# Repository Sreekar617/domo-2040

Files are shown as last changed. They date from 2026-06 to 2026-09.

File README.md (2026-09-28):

# domo-2040
A custom microcontroller built around the RP2040





## Features
* RP2040 microcontroller
* 27 GPIO pins
* 16MB flash memory
* Onboard user button (GPIO24)
* Onboard user LED (GPIO25)
* USB-C connection
* Compatible with Pi Pico footprint
* Super cool decoration
* Cute Domos
## Why?
I use devboards like the Pi Pico all the time, but I never really understood how they worked or anything. Specifically, I was curious as to why projects tend to use premade devboards such as Pi Picos rather than just use a plain RP2040. So naturally, I decided the best way to learn was to make one myself. Also, funnily enough the BOM comes out to about half the retail price of the Pico before countimg one-time assembly fees, which means if I were to theoretically mass produce this me and my friends could get devboards at about half price. 
## BOM
| Component | Specification | Quantity | LCSC Part # | Price |
|---|---|---|---|---|
| Capacitor 0402 | 1uF | 2 | C52923 | $0.02 |
| Capacitor 0402 | 0.1uF | 11 | C1525 | $0.06 |
| Capacitor 0402 | 33pF | 2 | C1562 | $0.02 |
| Capacitor 0603 | 10uF | 2 | C19702 | $0.20 |
| Diode SOD-323 | Schottky | 1 | C191023 | $0.02 |
| LED 0603 | White LED | 1 | C2290 | $0.02 |
| USB C Receptacle | USB C | 1 | C2765186 | $0.21 |
| Resistor 0402 | 5.1k | 2 | C25905 | $0.01 |
| Resistor 0402 | 27 | 2 | C25156 | $0.02 |
| Resistor 0402 | 1k | 3 | C11702 | $0.02 |
| Resistor 0402 | 10k | 2 | C25744 | $0.01 |
| Switch | Alps SKRK | 2 | C720477 | $0.11 |
| MCU | RP2040 | 1 | C2040 | $2.00 |
| Flash Chip | 128Mbit | 1 | C97521 | $2.65 |
| LDO SOT-23 | 5v->3v3 | 1 | C5446 | $0.20 |
| Crystal | 12MHz | 1 | C9002 | $0.20 |
| ~~**Soldering Iron**~~ | | 1 | stole it from a friend lol |~~$20~~ |

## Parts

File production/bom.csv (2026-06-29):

Designator | Footprint | Quantity | Value | LCSC Part #
C1, C12 | 0402 | 2 | 1uF | C52923
C10, C11, C17, C2, C3, C4, C5, C6, C7, C8, C9 | 0402 | 11 | 0.1uF | C1525
C13, C14 | 0402 | 2 | 33pF | C1562
C15, C16 | 0603 | 2 | 10uF | C19702
D1 | D_SOD-323 | 1 | 1N5819WS | C191023
D2 | 0603 | 1 | LED | C2290
J1 | USB_C_Receptacle_HRO_TYPE-C-31-M-12 | 1 | USB_C_Receptacle_USB2.0_14P | C2765186
J2, J3 | PinHeader_1x20_P2.54mm_Vertical | 2 | Conn_01x20 | C50981
J4 | PinHeader_1x03_P2.54mm_Vertical | 1 | Conn_01x03 | C24980
R1, R2 | 0402 | 2 | 5.1k | C25905
R3, R4 | 0402 | 2 | 27 | C25156
R5, R7, R8 | 0402 | 3 | 1k | C11702
R6, R9 | 0402 | 2 | 10k | C25744
SW1, SW2 | SW_Push_SPST_NO_Alps_SKRK | 2 | SW_Push | C720477
U1 | QFN-56-1EP_7x7mm_P0.4mm_EP3.2x3.2mm | 1 | RP2040 | C2040
U3 | SOIC-8_5.3x5.3mm_P1.27mm | 1 | W25Q128JVS | C97521
U4 | SOT-23 | 1 | MCP1700x-330xxTT | C5446
Y1 | Crystal_SMD_3225-4Pin_3.2x2.5mm | 1 | 12MHz | C9002

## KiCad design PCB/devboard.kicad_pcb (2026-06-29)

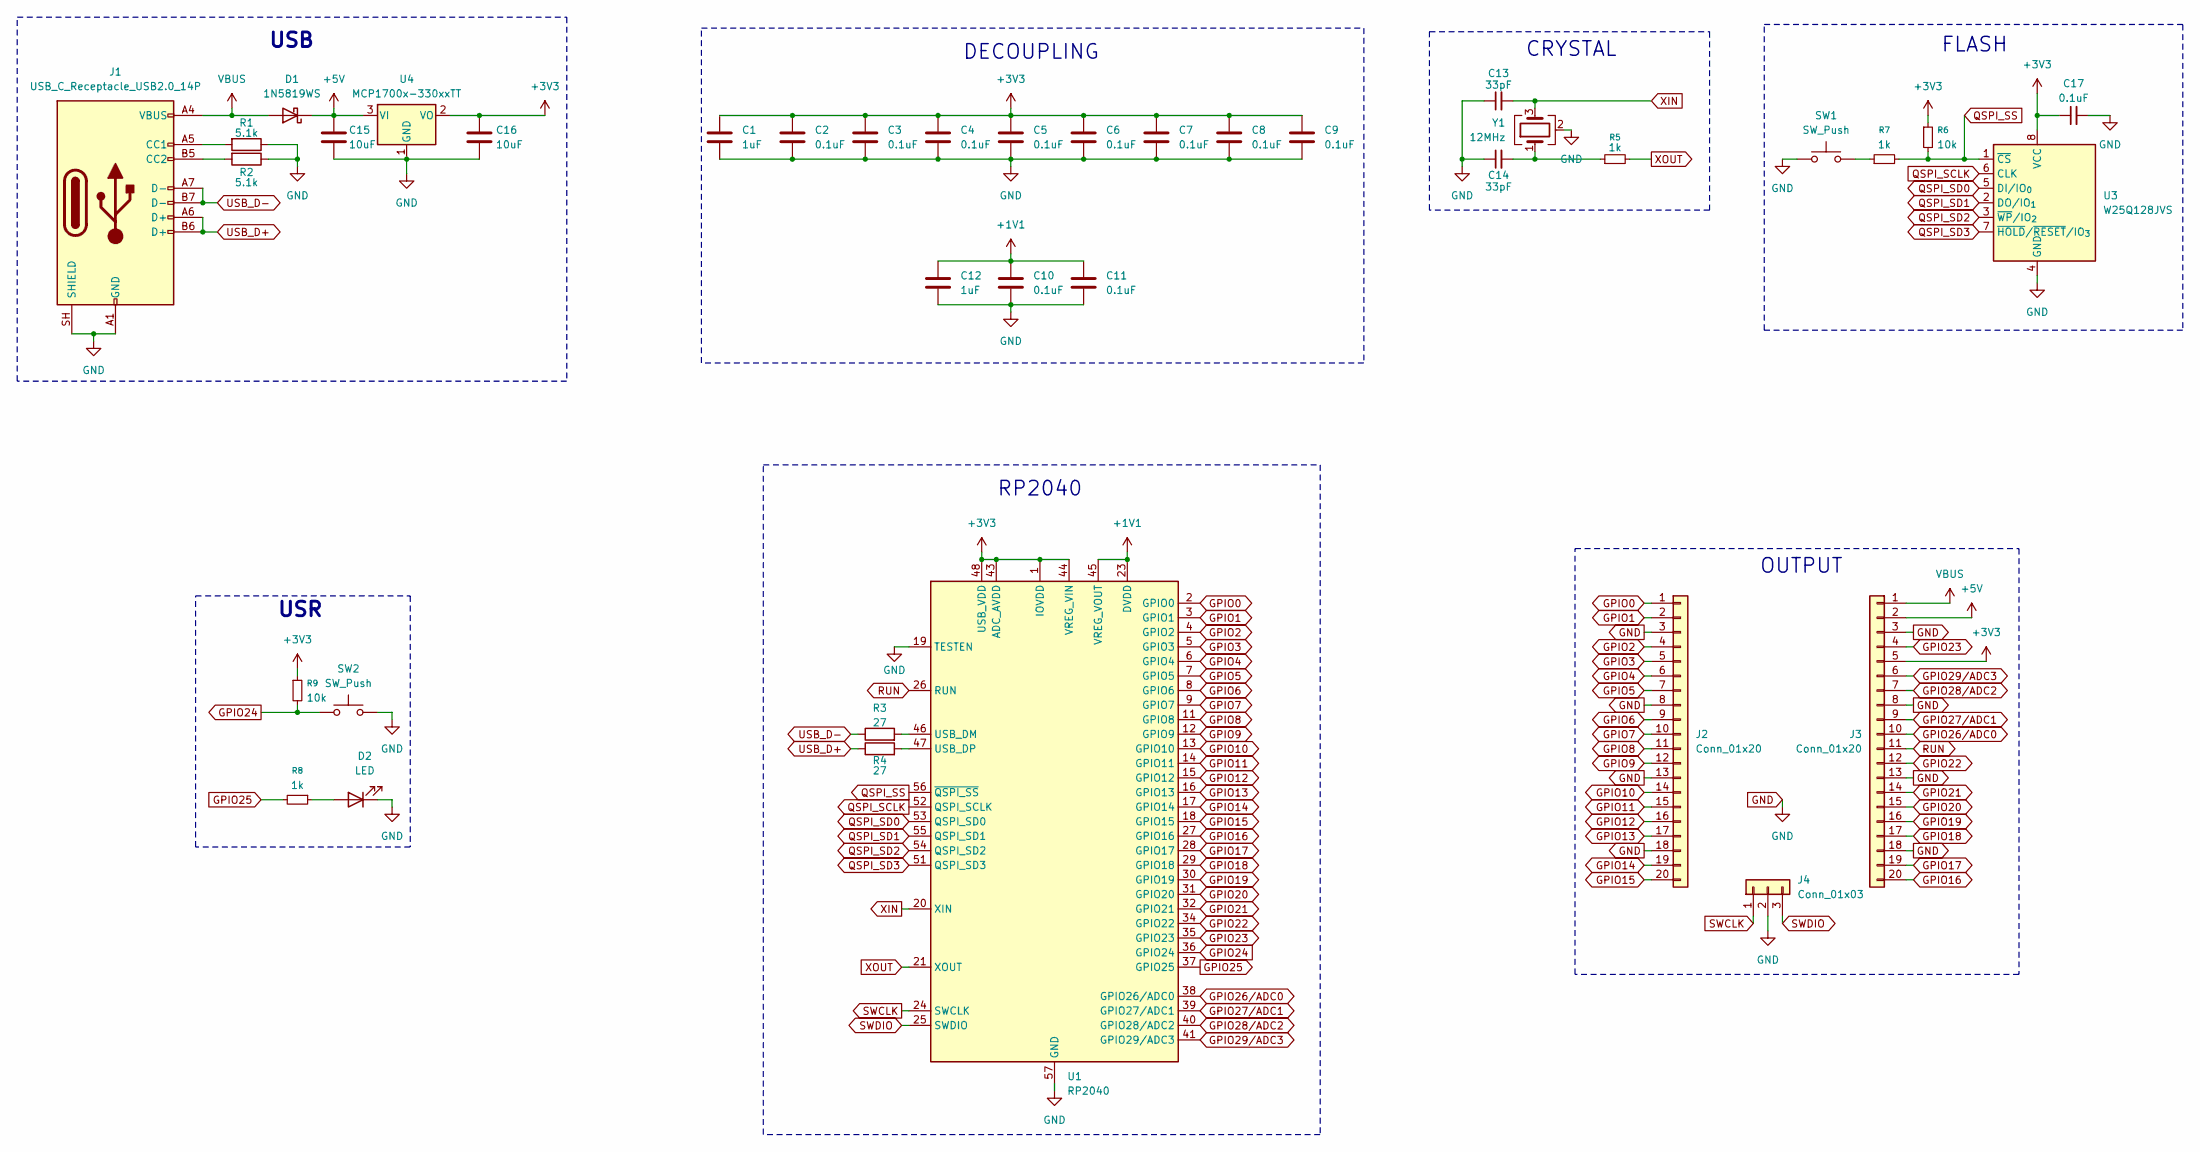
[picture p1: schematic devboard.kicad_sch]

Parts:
C1, C12: 1uF; C_0402_1005Metric; LCSC Part # C52923
C2, C3, C4, C5, C6, C7, C8, C9, C10, C11, C17: 0.1uF; C_0402_1005Metric; LCSC Part # C1525
C13, C14: 33pF; C_0402_1005Metric; LCSC Part # C1562
C15, C16: 10uF; C_0603_1608Metric; LCSC Part # C19702
D1: 1N5819WS; D_SOD-323; LCSC Part # C191023
D2: LED; LED_0603_1608Metric; LCSC Part # C2288
J1: USB_C_Receptacle_USB2.0_14P; USB_C_Receptacle_HRO_TYPE-C-31-M-12; LCSC Part # C2765186
J2, J3: Conn_01x20; PinHeader_1x20_P2.54mm_Vertical; LCSC Part # C50981
J4: Conn_01x03; PinHeader_1x03_P2.54mm_Vertical; LCSC Part # C24980
R1, R2: 5.1k; R_0402_1005Metric; LCSC Part # C25905
R3, R4: 27; R_0402_1005Metric; LCSC Part # C25100
R5, R7, R8: 1k; R_0402_1005Metric; LCSC Part # C11702
R6, R9: 10k; R_0402_1005Metric; LCSC Part # C25744
SW1, SW2: SW_Push; SW_Push_SPST_NO_Alps_SKRK; LCSC Part # C720477
U1: RP2040; QFN-56-1EP_7x7mm_P0.4mm_EP3.2x3.2mm; LCSC Part # CF2040
U3: W25Q128JVS; SOIC-8_5.3x5.3mm_P1.27mm; LCSC Part # C97521
U4: MCP1700x-330xxTT; SOT-23; LCSC Part # C5446
Y1: 12MHz; Crystal_SMD_3225-4Pin_3.2x2.5mm; LCSC Part # C9002

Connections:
+1V1: C10.1, C11.1, C12.1, U1.23 (DVDD), U1.45 (VREG_VOUT), U1.50 (DVDD)
+3V3: C1.1, C2.1, C3.1, C4.1, C5.1, C6.1, C7.1, C8.1, C9.1, C16.1, C17.1, J3.5, R6.1, R9.1, U1.1 (IOVDD), U1.10 (IOVDD), U1.22 (IOVDD), U1.33 (IOVDD), U1.42 (IOVDD), U1.43 (ADC_AVDD), U1.44 (VREG_VIN), U1.48 (USB_VDD), U1.49 (IOVDD), U3.8 (VCC), U4.2 (VO)
+5V: C15.1, D1.1 (K), J3.2, U4.3 (VI)
GND: C1.2, C2.2, C3.2, C4.2, C5.2, C6.2, C7.2, C8.2, C9.2, C10.2, C11.2, C12.2, C13.1, C14.1, C15.2, C16.2, C17.2, D2.1 (K), J1.A1 (GND), J1.A12 (GND), J1.B1 (GND), J1.B12 (GND), J1.SH (SHIELD), J2.3, J2.8, J2.13, J2.18, J3.3, J3.8, J3.13, J3.18, J4.2, R1.1, R2.1, SW1.1, SW2.2, U1.19 (TESTEN), U1.57 (GND), U3.4 (GND), U4.1 (GND), Y1.2 (G), Y1.4 (G)
GPIO0: J2.1, U1.2 (GPIO0)
GPIO1: J2.2, U1.3 (GPIO1)
GPIO2: J2.4, U1.4 (GPIO2)
GPIO3: J2.5, U1.5 (GPIO3)
GPIO4: J2.6, U1.6 (GPIO4)
GPIO5: J2.7, U1.7 (GPIO5)
GPIO6: J2.9, U1.8 (GPIO6)
GPIO7: J2.10, U1.9 (GPIO7)
GPIO8: J2.11, U1.11 (GPIO8)
GPIO9: J2.12, U1.12 (GPIO9)
GPIO10: J2.14, U1.13 (GPIO10)
GPIO11: J2.15, U1.14 (GPIO11)
GPIO12: J2.16, U1.15 (GPIO12)
GPIO13: J2.17, U1.16 (GPIO13)
GPIO14: J2.19, U1.17 (GPIO14)
GPIO15: J2.20, U1.18 (GPIO15)
GPIO16: J3.20, U1.27 (GPIO16)
GPIO17: J3.19, U1.28 (GPIO17)
GPIO18: J3.17, U1.29 (GPIO18)
GPIO19: J3.16, U1.30 (GPIO19)
GPIO20: J3.15, U1.31 (GPIO20)
GPIO21: J3.14, U1.32 (GPIO21)
GPIO22: J3.12, U1.34 (GPIO22)
GPIO23: J3.4, U1.35 (GPIO23)
GPIO24: R9.2, SW2.1, U1.36 (GPIO24)
GPIO25: R8.2, U1.37 (GPIO25)
GPIO26/ADC0: J3.10, U1.38 (GPIO26/ADC0)
GPIO27/ADC1: J3.9, U1.39 (GPIO27/ADC1)
GPIO28/ADC2: J3.7, U1.40 (GPIO28/ADC2)
GPIO29/ADC3: J3.6, U1.41 (GPIO29/ADC3)
unnamed: C14.2, R5.1, Y1.1
unnamed: D2.2 (A), R8.1
unnamed: J1.A5 (CC1), R1.2
unnamed: J1.B5 (CC2), R2.2
unnamed: R7.1, SW1.2
unnamed: R3.2, U1.46 (USB_DM)
unnamed: R4.2, U1.47 (USB_DP)
QSPI_SCLK: U1.52 (QSPI_SCLK), U3.6 (CLK)
QSPI_SD0: U1.53 (QSPI_SD0), U3.5 (DI/IO_{0})
QSPI_SD1: U1.55 (QSPI_SD1), U3.2 (DO/IO_{1})
QSPI_SD2: U1.54 (QSPI_SD2), U3.3 (~WP/IO_{2})
QSPI_SD3: U1.51 (QSPI_SD3), U3.7 (~HOLD/~RESET/IO_{3})
QSPI_SS: R6.2, R7.2, U1.56 (~QSPI_SS), U3.1 (~CS)
RUN: J3.11, U1.26 (RUN)
SWCLK: J4.1, U1.24 (SWCLK)
SWDIO: J4.3, U1.25 (SWDIO)
USB_D+: J1.A6 (D+), J1.B6 (D+), R4.1
USB_D-: J1.A7 (D-), J1.B7 (D-), R3.1
VBUS: D1.2 (A), J1.A4 (VBUS), J1.A9 (VBUS), J1.B4 (VBUS), J1.B9 (VBUS), J3.1
XIN: C13.2, U1.20 (XIN), Y1.3
XOUT: R5.2, U1.21 (XOUT)

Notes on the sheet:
USB
DECOUPLING
RP2040
FLASH
CRYSTAL
OUTPUT
USR

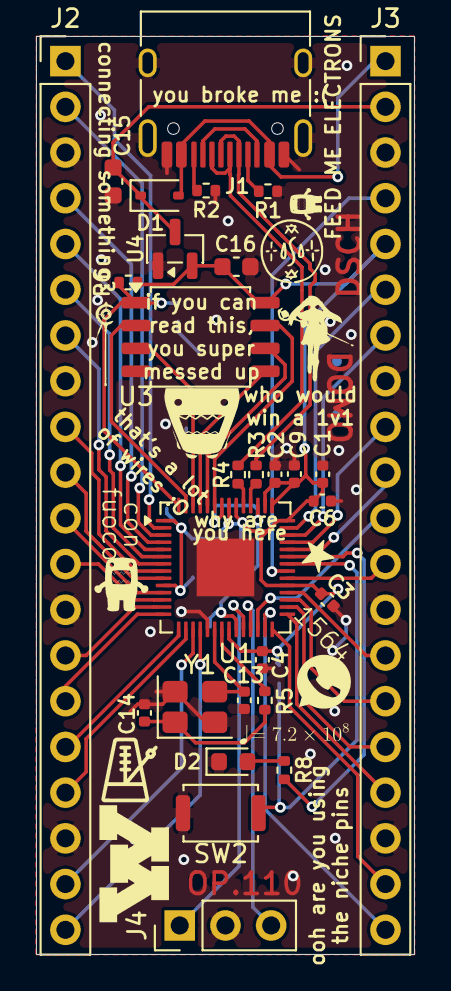
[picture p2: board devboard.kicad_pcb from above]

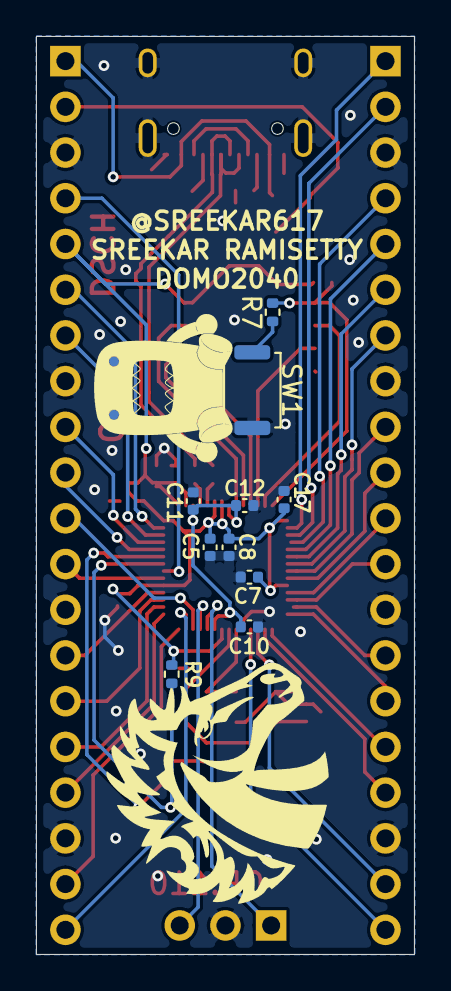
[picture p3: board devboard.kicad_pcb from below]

Board: 2 copper layers, 21.0 x 51.0 mm, 38 parts (10 on the bottom side), 55 nets.

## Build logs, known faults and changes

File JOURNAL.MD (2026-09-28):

Using [Kai Pereira's devboard tutorial](https://blueprint.hackclub.com/starter-projects/devboard), I was able to get a schematic together relatively quickly. The decoupling capacitors were kinda confusing at first, but then I checked the datasheet and it made sense that since there were 8 3v3 outputs you'd use 8 capacitors for 3v3


## USB
Starting at the top left, USB is the USB-C connection because wireless power isn't good enough yet and micro usb is trash. The CC lines are pulled to GND via 5.1k resistors as specified by the datasheet.  Data is transmitted via D- and D+, and there's two identical outputs for each line. I just have them connected to a single line and connected to the MCU via 27 ohm resistors. The power given by the USB C receptacle is 5V, so i use an LDO to step it down to 3V3 which is much tastier and can efffectively juice up not just the components on the pcb but also any external components i may want to connect to the devboard. both the 5V and 3.3V lines have bulk caps to smooth out large voltage ripples caused by the LDO not being a massless frictionless ideal gas. 

## DECOUPLING
This is pretty simple, there's eight small 3V3 capacitors and two 1V1 capacitors to filter out high frequency noise, one per output on the chip, and then a larger decoupling capacitor for each of the lines.


## CRYSTAL
This is a super tuff crystal that oscillates at a known frequency to help the MCU time stuff. It needs two 33pF (tiny!) external load capacitors to work for some super cool math reasons i don't really understand. It's connected to the MCU through a 1k damping resistor that protects it.


## FLASH
I deviated from the tutorial a bit here and used a 16MB flash chip instead of the 2MB that the tutorial used, so hopefully that'll be fine. It communicates with the MCU using quad SPI for fast data transfer. Side note, the widely used terms to talk about SPI are master and slave, but the other (and imo better) way to say it is controller and peripheral. However, it's labeled both ways on my schematic so bear with me a little. When the Slave Select (or Chip Select) pin on the flash is pulled to ground, it acts as a reset signal, so that's what the 1k, SW, and GND are for. The rest of the time, it has to be pulled to HIGH, so we have a 10k resistor connected to 3V3 to pull up the CS pin the rest of the time. There's a 0.1uF decoupling capacitor next to the power, and there's four data lines going back to the MCU (hence quad spi)


## RP2040/OUTPUT
There's nothing super crazy going on here, from my side I just connect all the peripherals back to this, and also make sure to connect the GPIO outputs and whatnot to the header pins.


# PCB -- Edge.Cuts, Placement, and Caps (~3 hours)
The first thing I did on the PCB was make the Edge.Cuts, since I want this to be able to match the footprint of a normal Pico I matched the dimensions. I then placed down all the big components, and placed the decoupling capacitors as close as I could to the things they were supposed to decouple. Following the advice of the guide, I tried to wire the high speed components first, without using any vias. Using the 16MB chip made it kinda hard since it's just so bulky, but eventually I got it wired pretty good. The USB-C data lines needed to be differential pairs, and they needed to be exactly the same length, but I tried for a while and I could not figure out how to use the length tuning tool, so I ended up just adding a little kink by hand.i was confused about some simple things (like "will the usb c port fit underneath the board") so i tried asking the big claude and the big gpt but they were completely useless so i had to actually lock in and solve my problems on my own.


# PCB -- Routing  (~3 hours)
This was definitely the hardest part. I just sat in front of the Kicad and tried different variations on routing until I found one that was satisfactory. I had to move some of the capacitors out of the way to make space, and I ended up putting some of them underneath the chip, on the back side. The bulky 16MB chip really overcomplicated this, but at this point I was reluctant to change it out so I tried my best to work around it. Once I had all the resistors and stuff down, I had to route the 40ish header pins, which were less strict about speed and impedance and stuff so I could use vias for those. 


# PCB -- Debug (~4 hours)
This was a lot of running DRC, fixing the error that came up, then running DRC and fixing the two more that pop up in its place. One thing I encoutered a lot is incomplete thermal relief where there was only one spoke instead of two spokes: 
I fixed this by just extending a small trace outwards from the pad, which is a solution i read somewhere on Slack and seemed to appease DRC. 
Also, there were sections of the ground pour that were kinda just floating and not actually connected to ground, so I added some more vias to fix that. I also cleaned up some of the suboptimal routing, and fixed some of the text being too small to print properly. Also there was some basic stuff like a couple traces/vias accidentally placed too close to each other but that was pretty simple to fix.
# Back to the schematic (~2 hours)
I decided it was too cringe to not deviate from the original Pico design, so I decided to make use of every pin on the rp2040, and also use every single header pin on the 1x20 connectors. My original design had GP25 marked as N/C, and both the original Pico and the Orpheus Pico have two N/C pins on the headers (well technically theyre not NC on the pico but they're basically useless to normal people). After some tweaks to the schematic, I added a user LED so it can look cool and light up, and I added another button for user input, using all the GPIO pins on the RP2040. Then, I shuffled around the header pins a bit and added one GP pin so all the slots are used, but I did my best to make it still compatible with normal Pico uses so it won't explode or something.
tuff schematic

# low cortisol decorating

# oops there's a catastrophic error (~2 hours)
it turns out all of the 3v3 traces need to be connected to **each other** and not just to their own capacitor so i had to reposition a bunch of the capacitors to make it possible to connect them together. This was pretty hard because at this stage of the design, a lot of stuff was already placed down, and i kinda had to place capacitors around the stuff.
Here's a picture of the error (notice the thin cyan lines showing it's unconnected):

and here's my solution 😭:


# ship it
It was kind of hard to figure out how to get everything ordered and how not to bankrupt four generations of my family for a piece of copper but i eventually figured it out and i'm glad i learned how to order pcba from JLC

# build it (1 hour)
It took a while to solder the tiny components, and I accidentally messed up the resistor connected to the LED so i had to make an emergency repair to make the user LED work without resoldering an 0402 resistor but it works now yay 
video https://cdn.hackclub.com/01a0e574-c0dc-76d3-b759-e71435e16d3c/IMG_4351.mp4

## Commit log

2026-06-29 add gerbers
2026-06-29 add bom
    [bom.csv]
2026-06-29 add pcb design files
    [devboard.kicad_pcb, devboard.kicad_sch]
2026-06-29 update production files
    [positions.csv]
2026-06-29 reformat production files for JLC
    [bom.csv]
